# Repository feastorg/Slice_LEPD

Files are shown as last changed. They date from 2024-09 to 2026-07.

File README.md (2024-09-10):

# Photometer Slice

Photometer using LED and photodiode slice for BREAD.

## Introduction

[Short introduction on the project.]

## Usage

[Explain how to use the project. Include examples and screenshots if applicable.]

## Documentation

Please refer to the [docs](/docs) for more info.

---

<div align="center">
  <p>
    
    
  </p>
</div>

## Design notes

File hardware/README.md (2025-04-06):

# LED-Photodiode Optical Density Meter

## Parts

- LEDs
  - PD: SFH 213 FA
  - IR: INL-5AMIR15
  - from: https://forum.pioreactor.com/t/od600-or-900-what-is-the-part-number-for-the-ir-led-and-photodiode/375

## Subcomponents

1. **PWM-to-DAC Filter (Lower Left)**

   - **Input:** A PWM signal enters through an RC network (two resistors and two capacitors) that smooths it into a DC “DAC” voltage.
   - **Outputs:** This DAC voltage is fed to:
     - The noninverting (+) input of the LM339 comparator (top amplifier).
     - The noninverting (+) input of the MCP6242 op amp (bottom amplifier).

2. **LM339 Comparator (Top)**

   - **+ Input:** Receives the filtered DAC voltage.
   - **− Input:** Receives a reference or filtered voltage derived from the +5 V rail.
   - **Output:**
     - Uses an open-collector configuration with a pull-up resistor (1 kΩ) to the +5 V rail.
     - A 200 kΩ resistor from the output back to the DAC input provides hysteresis.
     - The comparator output drives the base of the BC858 PNP transistor through a 10 kΩ resistor.

3. **BC858 PNP Transistor (Top Switch)**

   - **Collector:** Connected directly to the +5 V rail.
   - **Base:** Driven by the LM339 comparator output (via a 10 kΩ resistor).
   - **Emitter:** Connected to the common output node, which is shared with:
     - The drain of the BSS806 N-channel MOSFET.
     - The cathode of the LED (which is further protected by a TVS diode).

4. **MCP6242 Op Amp (Bottom)**

   - **+ Input:** Receives the same DAC voltage from the PWM filter.
   - **− Input:** Connected to the source of the BSS806 MOSFET (the voltage sensed across a 10 Ω resistor).
   - **Output:** Drives the gate of the BSS806 MOSFET (labeled “FET_GATE”) to regulate current.

5. **BSS806 N-Channel MOSFET (Bottom Switch)**

   - **Drain:** Tied to the common output node (also the emitter of the BC858).
   - **Source:** Connects to a 10 Ω resistor that goes to ground. This resistor acts as a current-sense element.
   - **Function:** Controlled by the op amp to regulate the voltage at the source, and hence the current through the LED.

6. **LED and 10 Ω Sense Resistor**

   - **LED Anode:** Connected to the +5 V rail.
   - **LED Cathode:** Connected to the common node (junction of BC858 emitter and MOSFET drain).
   - **Current Path:** +5 V → LED → common node → MOSFET → 10 Ω resistor → Ground.
   - **Sensing:** The voltage across the 10 Ω resistor is used by the op amp for current regulation.

7. **TVS Diode (DF2S6.8M)**
   - **Connection:** Placed between the common output node and ground.
   - **Function:** Provides transient and ESD protection to the circuit.

---

## 2) Overall Function and How It Works

1. **PWM Filtering to Create a DAC:**  
   A low-pass RC filter converts a PWM signal into a stable DC voltage. This voltage represents the desired setpoint for the LED current or voltage.

2. **Op Amp and MOSFET Current Regulation:**

   - The MCP6242 op amp compares the DAC setpoint with the voltage at the MOSFET source (across the 10 Ω sense resistor).
   - Based on this comparison, the op amp adjusts the gate voltage of the BSS806 MOSFET.
   - This regulation maintains the correct current through the LED by ensuring that the sensed voltage (proportional to current) matches the DAC setpoint.

3. **Comparator and PNP Transistor Threshold Control:**

   - The LM339 comparator monitors the DAC voltage against a reference (from the +5 V supply).
   - Through its open-collector output (with hysteresis via the 200 kΩ resistor), it determines if the operating condition is within the desired range.
   - The comparator’s output drives the BC858 PNP transistor, which can provide an alternate current path or act as a switch to either enable or limit the LED current based on threshold conditions.

4. **Combined Regulation and Protection:**
   - **Current Flow:** The LED current flows from the +5 V rail through the LED, into the common node, through the MOSFET, and finally through the 10 Ω resistor to ground.
   - **Protection:** A TVS diode is connected at the output node to guard against voltage spikes.
   - **Feedback:** The op amp continuously adjusts the MOSFET’s gate voltage to ensure that the voltage across the 10 Ω resistor (and thus the LED current) matches the desired value set by the DAC voltage.

**In summary:**  
The circuit converts a PWM signal to a DC level that serves as a setpoint for LED current. The op amp and MOSFET form a linear regulator that adjusts the LED current, while the comparator and PNP transistor provide threshold-based switching or clamping for additional control and protection.

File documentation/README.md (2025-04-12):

# LED-Photodiode Optical Density Meter

## Parts

- LEDs
  - PD: SFH 213 FA
  - IR: INL-5AMIR15
  - from: https://forum.pioreactor.com/t/od600-or-900-what-is-the-part-number-for-the-ir-led-and-photodiode/375

- Connectors
  - Molex pico blade: https://www.digikey.ca/en/products/detail/molex/0530480210/242864?s=N4IgTCBcDaIKwGYAMAWAHEsBGJIC6AvkA

- LED driver sense resistor
  - https://www.digikey.ca/en/products/detail/stackpole-electronics-inc/RMCF1210FT10R0/1758534
  - 1/2W 1% 1210 (3225 Metric)

## LED Driver

Goal: drive an LED at a set constant current via a PWM signal to produce a consistent light level.

Purpose: we want the LED to emit a set light level with high accuracy (known) and precision (low noise).

### Subcomponents

1. **PWM-to-DAC Filter (Lower Left)**

   - **Input:** A PWM signal enters through an RC network (two resistors and two capacitors) that smooths it into a DC “DAC” voltage.
   - **Outputs:** This DAC voltage is fed to:
     - The noninverting (+) input of the LM339 comparator (top amplifier).
     - The noninverting (+) input of the MCP6242 op amp (bottom amplifier).

2. **LM339 Comparator (Top)**

   - **+ Input:** Receives the filtered DAC voltage.
   - **− Input:** Receives a reference or filtered voltage derived from the +5 V rail.
   - **Output:**
     - Uses an open-collector configuration with a pull-up resistor (1 kΩ) to the +5 V rail.
     - A 200 kΩ resistor from the output back to the DAC input provides hysteresis.
     - The comparator output drives the base of the BC858 PNP transistor through a 10 kΩ resistor.

3. **BC858 PNP Transistor (Top Switch)**

   - **Collector:** Connected directly to the +5 V rail.
   - **Base:** Driven by the LM339 comparator output (via a 10 kΩ resistor).
   - **Emitter:** Connected to the common output node, which is shared with:
     - The drain of the BSS806 N-channel MOSFET.
     - The cathode of the LED (which is further protected by a TVS diode).

4. **MCP6242 Op Amp (Bottom)**

   - **+ Input:** Receives the same DAC voltage from the PWM filter.
   - **− Input:** Connected to the source of the BSS806 MOSFET (the voltage sensed across a 10 Ω resistor).
   - **Output:** Drives the gate of the BSS806 MOSFET (labeled “FET_GATE”) to regulate current.

5. **BSS806 N-Channel MOSFET (Bottom Switch)**

   - **Drain:** Tied to the common output node (also the emitter of the BC858).
   - **Source:** Connects to a 10 Ω resistor that goes to ground. This resistor acts as a current-sense element.
   - **Function:** Controlled by the op amp to regulate the voltage at the source, and hence the current through the LED.

6. **LED and 10 Ω Sense Resistor**

   - **LED Anode:** Connected to the +5 V rail.
   - **LED Cathode:** Connected to the common node (junction of BC858 emitter and MOSFET drain).
   - **Current Path:** +5 V → LED → common node → MOSFET → 10 Ω resistor → Ground.
   - **Sensing:** The voltage across the 10 Ω resistor is used by the op amp for current regulation.

7. **TVS Diode (DF2S6.8M)**
   - **Connection:** Placed between the common output node and ground.
   - **Function:** Provides transient and ESD protection to the circuit.

---

### Function and Theory of Operation

1. **PWM Filtering to Create a DAC:**  
   A low-pass RC filter converts a PWM signal into a stable DC voltage. This voltage represents the desired setpoint for the LED current or voltage.

2. **Op Amp and MOSFET Current Regulation:**

   - The MCP6242 op amp compares the DAC setpoint with the voltage at the MOSFET source (across the 10 Ω sense resistor).
   - Based on this comparison, the op amp adjusts the gate voltage of the BSS806 MOSFET.
   - This regulation maintains the correct current through the LED by ensuring that the sensed voltage (proportional to current) matches the DAC setpoint.

3. **Comparator and PNP Transistor Threshold Control:**

   - The LM339 comparator monitors the DAC voltage against a reference (from the +5 V supply).
   - Through its open-collector output (with hysteresis via the 200 kΩ resistor), it determines if the operating condition is within the desired range.
   - The comparator’s output drives the BC858 PNP transistor, which can provide an alternate current path or act as a switch to either enable or limit the LED current based on threshold conditions.

4. **Combined Regulation and Protection:**
   - **Current Flow:** The LED current flows from the +5 V rail through the LED, into the common node, through the MOSFET, and finally through the 10 Ω resistor to ground.
   - **Protection:** A TVS diode is connected at the output node to guard against voltage spikes.
   - **Feedback:** The op amp continuously adjusts the MOSFET’s gate voltage to ensure that the voltage across the 10 Ω resistor (and thus the LED current) matches the desired value set by the DAC voltage.

**In summary:**  
The circuit converts a PWM signal to a DC level that serves as a setpoint for LED current. The op amp and MOSFET form a linear regulator that adjusts the LED current, while the comparator and PNP transistor provide threshold-based switching or clamping for additional control and protection.

## Photodiode Transimpedance amplifier

Goal: transduce the light level at the photodiode into a steady proportional current and transform this current into a proportional voltage that can be read.

Purpose: read the effective light level

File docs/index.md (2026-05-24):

---
title: "Slice LEPD Documentation"
description: "Overview and entry page for Slice LEPD project documentation."
nav_exclude: true
---

Welcome to the Slice LEPD project documentation.

## Board Renders

<figure style="display:inline-block; text-align:center; margin:10px;">
  Board Top
  <figcaption>Top</figcaption>
</figure>

<figure style="display:inline-block; text-align:center; margin:10px;">
  Board Bottom
  <figcaption>Bottom</figcaption>
</figure>

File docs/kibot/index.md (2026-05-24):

---
title: "KiBot Outputs"
description: "Index for KiBot-generated PCB artifacts."
layout: "page"
---

These are the docs & KiBot Outputs for Slice LEPD

The following files were generated from the latest PCB build:

- [Schematic.pdf](./Schematic.pdf)
- [PCB.pdf](./PCB.pdf)
- [kibot.log](./kibot.log)
- [BREAD_Slice-bom.html](./BREAD_Slice-bom.html)
- [BREAD_Slice-ibom.html](./BREAD_Slice-ibom.html)

_Last updated automatically by KiBot via GitHub Actions._

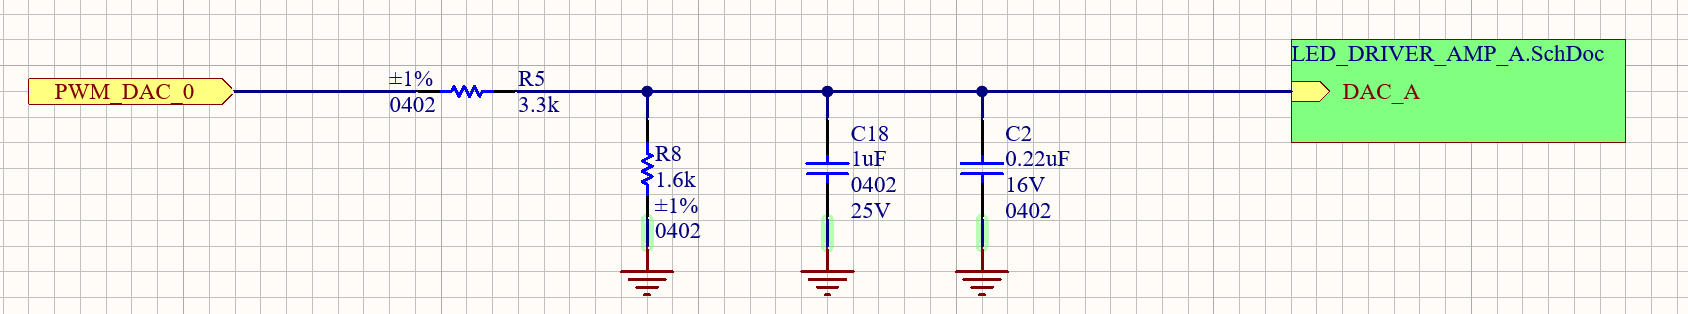
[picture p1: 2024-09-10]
hardware/pwm_dac0_to_led_driver_amp.png

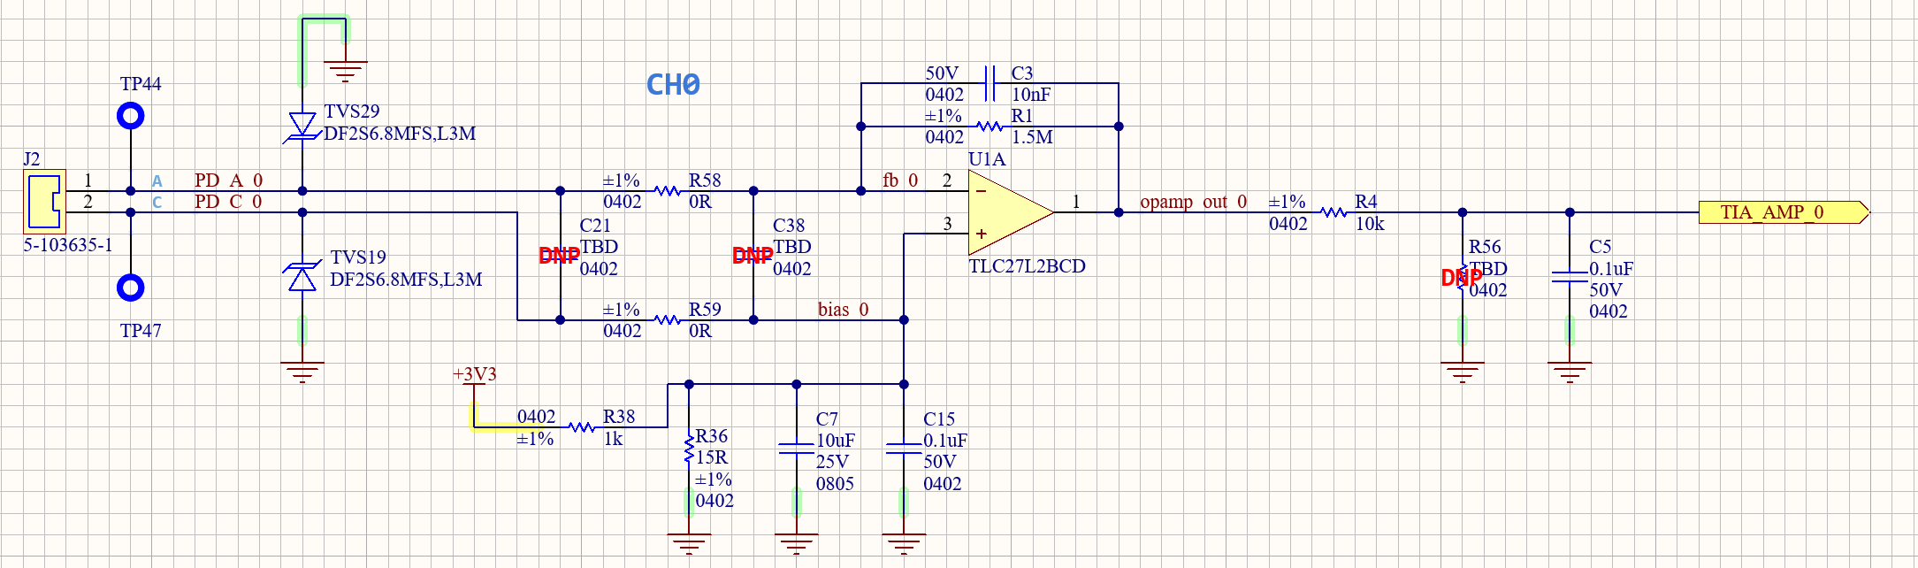
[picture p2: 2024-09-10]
hardware/pd_tia_amp.png

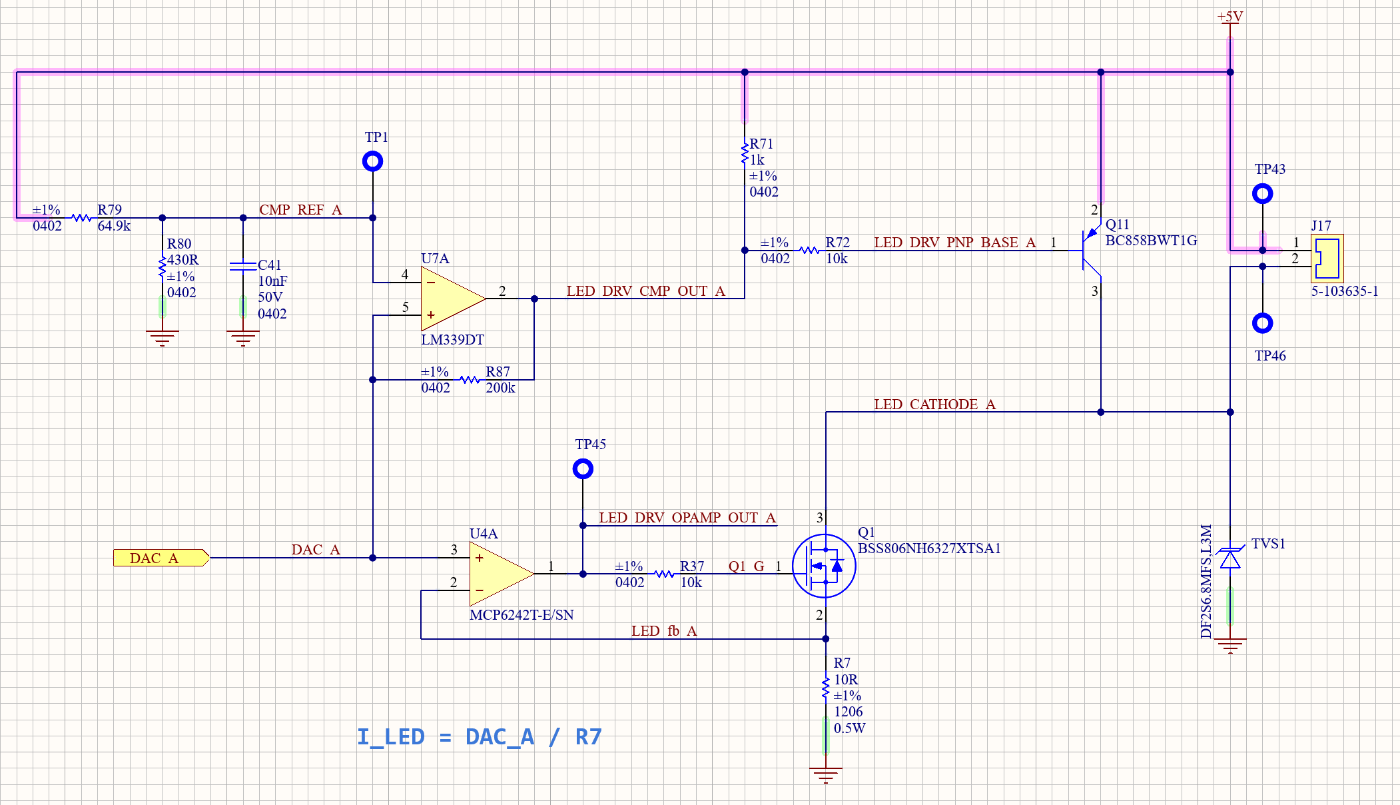
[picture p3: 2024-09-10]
hardware/led_driver_amp.png

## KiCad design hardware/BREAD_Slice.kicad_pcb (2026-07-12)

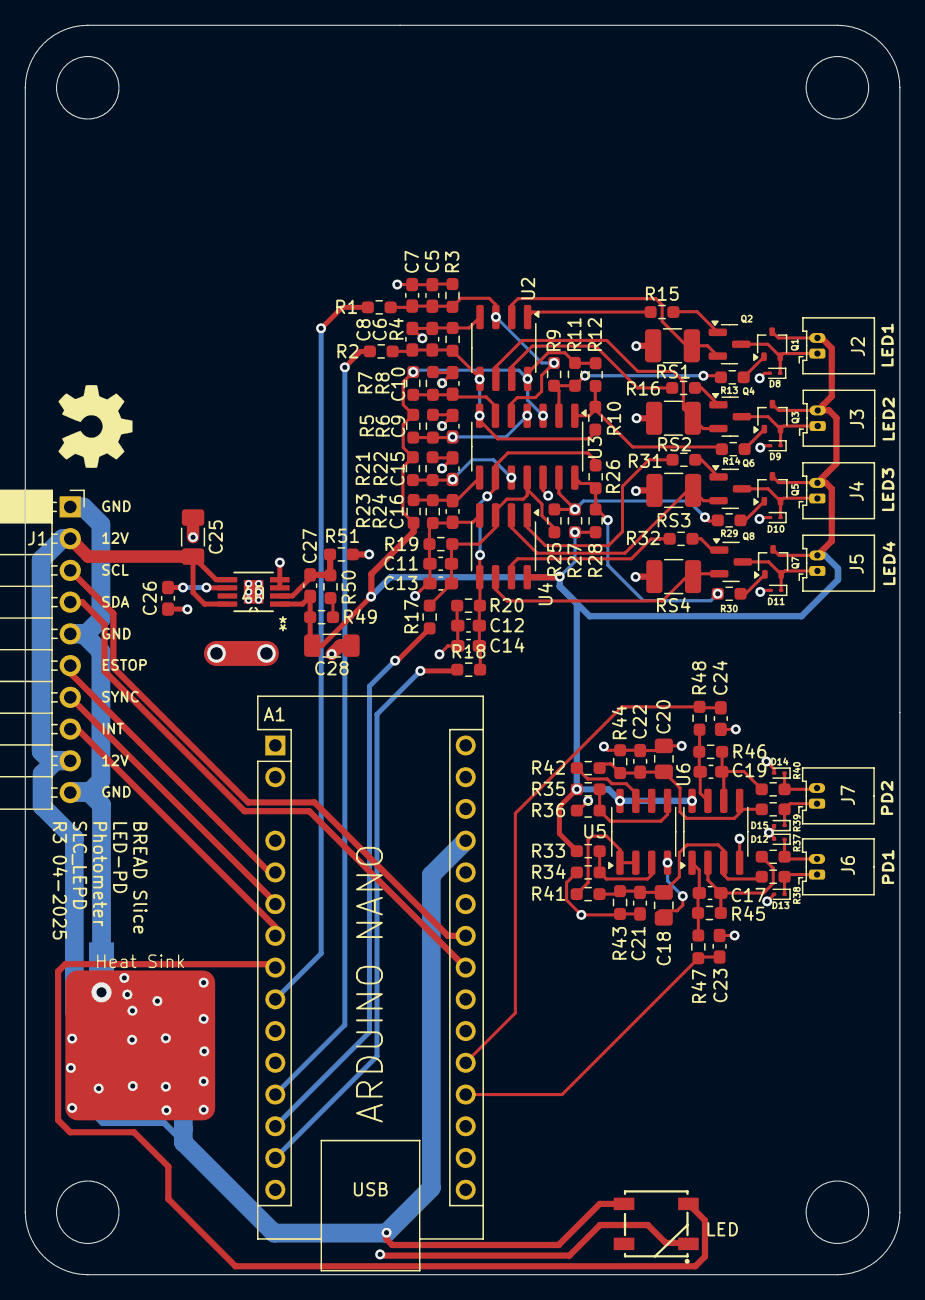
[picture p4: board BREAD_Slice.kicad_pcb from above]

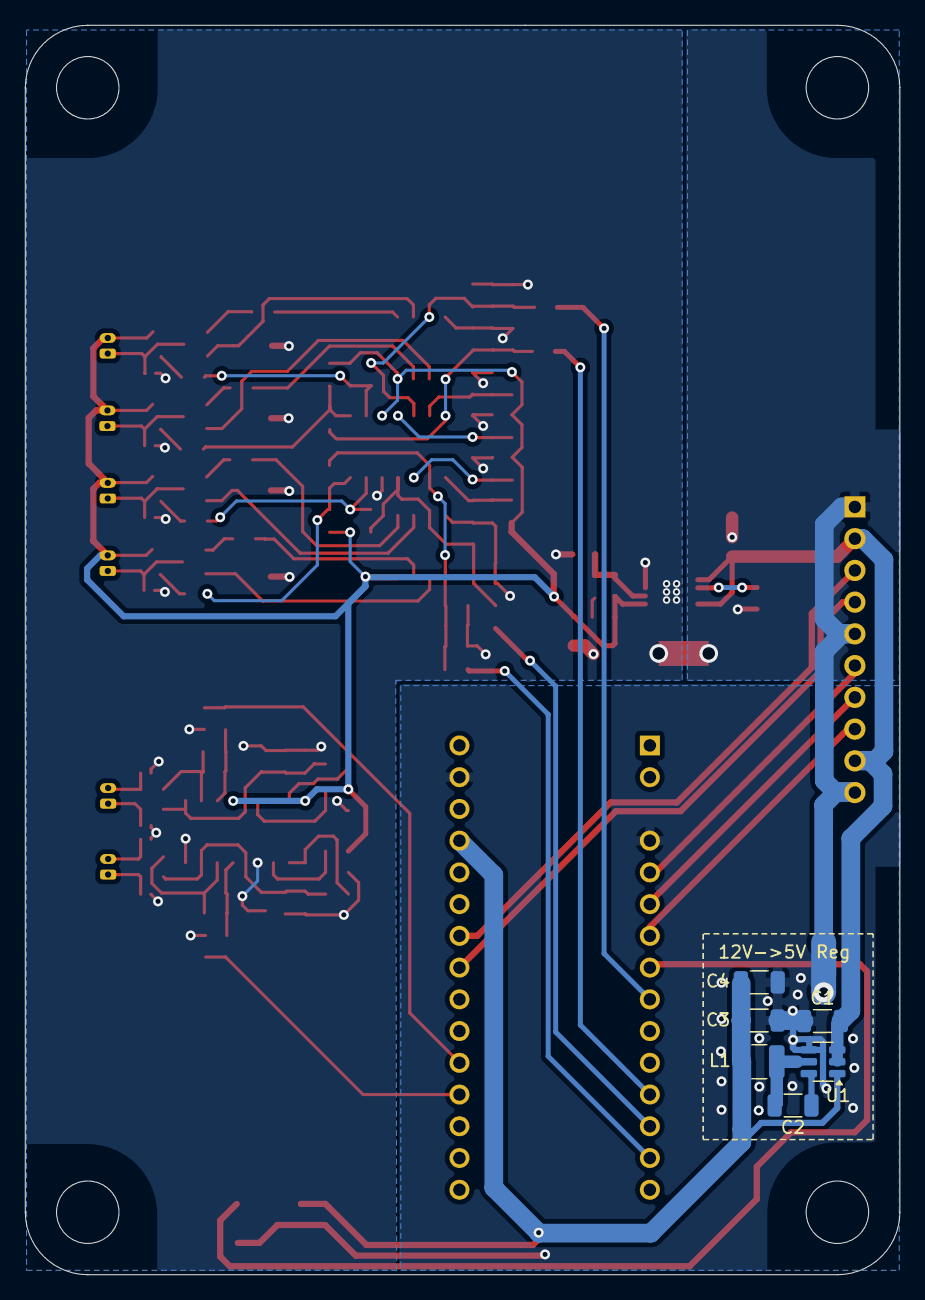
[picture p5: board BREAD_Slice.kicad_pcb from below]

Board: 2 copper layers, 70.0 x 100.0 mm, 124 parts (7 on the bottom side), 69 nets.

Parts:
A1: Arduino_Nano_v3.x; Arduino_Nano
C1, C3, C4: 22uF; C_1206_3216Metric
C2: 100nF; C_1206_3216Metric
C5, C6, C11, C12: 1u; C_0603_1608Metric_Pad1.08x0.95mm_HandSolder
C7, C8, C13, C14: 0.22u; C_0603_1608Metric_Pad1.08x0.95mm_HandSolder
C9, C10, C15, C16, C17, C19: 10n; C_0603_1608Metric_Pad1.08x0.95mm_HandSolder
C18, C20: 10u; C_0805_2012Metric_Pad1.18x1.45mm_HandSolder
C21, C22, C23, C24: 0.1u; C_0603_1608Metric_Pad1.08x0.95mm_HandSolder
C25, C28: 10u X7R; C_1206_3216Metric_Pad1.33x1.80mm_HandSolder
C26, C27: 10n X7R; C_0603_1608Metric_Pad1.08x0.95mm_HandSolder
D1: WS2812B_5050; WS2812-5050-4PIN
D8, D9, D10, D11, D12, D13, D14, D15: DF2S6.8MFS_L3M; D_SOD-923
H1, H2, H3, H4: MountingHole; MountingHole_5mm
HS1: Heatsink_Pad; Thermal_Pad
J1: Conn_01x10_Female; PinSocket_1x10_P2.54mm_Horizontal
J2, J3, J4, J5, J6, J7: Conn_01x02; Molex_PicoBlade_53048-0210_1x02_P1.25mm_Horizontal
L1: 4.7uH; L_1210_3225Metric
Logo1: Logo_Open_Hardware_Small; OSHW-Symbol_6.7x6mm_SilkScreen
NT1, NT2: NetTie_2; NetTie-2_SMD_Pad2.0mm
Q1, Q3, Q5, Q7: BC858BWT1G; SOT-323_SC-70
Q2, Q4, Q6, Q8: BSS806NH6327XTSA1; SOT-23
R1, R2, R17, R18: 3.3k 1%; R_0603_1608Metric_Pad0.98x0.95mm_HandSolder
R3, R4, R19, R20: 1.6k 1%; R_0603_1608Metric_Pad0.98x0.95mm_HandSolder
R5, R7, R21, R23: 64.9k 1%; R_0603_1608Metric_Pad0.98x0.95mm_HandSolder
R6, R8, R22, R24: 430 1%; R_0603_1608Metric_Pad0.98x0.95mm_HandSolder
R9, R10, R25, R26: 200k 1%; R_0603_1608Metric_Pad0.98x0.95mm_HandSolder
R11, R12, R27, R28, R41, R42: 1k 1%; R_0603_1608Metric_Pad0.98x0.95mm_HandSolder
R13, R14, R15, R16, R29, R30, R31, R32, R47, R48: 10k 1%; R_0603_1608Metric_Pad0.98x0.95mm_HandSolder
R33, R35: 10k; R_0603_1608Metric_Pad0.98x0.95mm_HandSolder
R34, R36: 20k; R_0603_1608Metric_Pad0.98x0.95mm_HandSolder
R37, R38, R39, R40: 0R; R_0603_1608Metric_Pad0.98x0.95mm_HandSolder
R43, R44: 15 1%; R_0603_1608Metric_Pad0.98x0.95mm_HandSolder
R45, R46: 1.5M 1%; R_0603_1608Metric_Pad0.98x0.95mm_HandSolder
R49: 300k 1%; R_0603_1608Metric_Pad0.98x0.95mm_HandSolder
R50: 71.5k 1%; R_0603_1608Metric_Pad0.98x0.95mm_HandSolder
R51: 100k 1%; R_0603_1608Metric_Pad0.98x0.95mm_HandSolder
RS1, RS2, RS3, RS4: 10 0.5W 1%; R_1210_3225Metric_Pad1.30x2.65mm_HandSolder
U1: AP63205; TSOT-23-6
U2, U4, U5: MCP6242T-E/SN; SOIC-8_3.9x4.9mm_P1.27mm
U3: LM339B; SOIC-14_3.9x8.7mm_P1.27mm
U6: TLV9142; SOIC-8_3.9x4.9mm_P1.27mm
U7: TPS7A4901DGNR; DGN8_1P89X1P57

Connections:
+5V: A1.27 (+5V), C3.2, C4.2, D1.1 (VDD), L1.2, U1.1 (FB)
+5VA: C27.2, C28.2, J2.2, J3.2, J4.2, J5.2, Q1.3 (C), Q3.3 (C), Q5.3 (C), Q7.3 (C), R5.2, R7.2, R11.1, R12.1, R21.2, R23.2, R27.1, R28.1, R33.1, R35.1, R49.2, U2.8 (V+), U3.3 (V+), U4.8 (V+), U5.8 (V+), U6.8 (V+), U7.1 (OUT)
+12V: C1.2, C25.2, J1.2, J1.9, U1.2 (EN), U1.3 (VIN), U7.5 (EN), U7.8 (IN)
/ESTOP: A1.5 (D2), J1.6
/I2C_CLK: A1.24 (A5), J1.3
/I2C_DAT: A1.23 (A4), J1.4
/INT: A1.6 (D3), J1.7
/LED: A1.8 (D5), D1.4 (DIN)
/Linear Constant‐Current LED Driver x4/COMP_OUT_1: R9.2, R11.2, R13.1, U3.2
/Linear Constant‐Current LED Driver x4/COMP_OUT_2: R10.2, R12.2, R14.1, U3.1
/Linear Constant‐Current LED Driver x4/COMP_OUT_3: R25.2, R27.2, R29.1, U3.13
/Linear Constant‐Current LED Driver x4/COMP_OUT_4: R26.2, R28.2, R30.1, U3.14
/Linear Constant‐Current LED Driver x4/COMP_REF_1: C9.1, R5.1, R6.1, U3.4 (-)
/Linear Constant‐Current LED Driver x4/COMP_REF_2: C10.1, R7.1, R8.1, U3.6 (-)
/Linear Constant‐Current LED Driver x4/COMP_REF_3: C15.1, R21.1, R22.1, U3.10 (-)
/Linear Constant‐Current LED Driver x4/COMP_REF_4: C16.1, R23.1, R24.1, U3.8 (-)
/Linear Constant‐Current LED Driver x4/DAC_1: C5.1, C7.1, R1.2, R3.1, R9.1, U2.3 (+), U3.5 (+)
/Linear Constant‐Current LED Driver x4/DAC_2: C6.1, C8.1, R2.2, R4.1, R10.1, U2.5 (+), U3.7 (+)
/Linear Constant‐Current LED Driver x4/DAC_3: C11.1, C13.1, R17.2, R19.1, R25.1, U3.11 (+), U4.3 (+)
/Linear Constant‐Current LED Driver x4/DAC_4: C12.1, C14.1, R18.2, R20.1, R26.1, U3.9 (+), U4.5 (+)
/Linear Constant‐Current LED Driver x4/FEEDBACK_1: Q2.2 (S), RS1.1, U2.2 (-)
/Linear Constant‐Current LED Driver x4/FEEDBACK_2: Q4.2 (S), RS2.1, U2.6 (-)
/Linear Constant‐Current LED Driver x4/FEEDBACK_3: Q6.2 (S), RS3.1, U4.2 (-)
/Linear Constant‐Current LED Driver x4/FEEDBACK_4: Q8.2 (S), RS4.1, U4.6 (-)
/Linear Constant‐Current LED Driver x4/LED_CATHODE_1: D8.1, J2.1, Q1.2 (E), Q2.3 (D)
/Linear Constant‐Current LED Driver x4/LED_CATHODE_2: D9.1, J3.1, Q3.2 (E), Q4.3 (D)
/Linear Constant‐Current LED Driver x4/LED_CATHODE_3: D10.1, J4.1, Q5.2 (E), Q6.3 (D)
/Linear Constant‐Current LED Driver x4/LED_CATHODE_4: D11.1, J5.1, Q7.2 (E), Q8.3 (D)
/Linear Constant‐Current LED Driver x4/NFET_GATE_1: Q2.1 (G), R15.2
/Linear Constant‐Current LED Driver x4/NFET_GATE_2: Q4.1 (G), R16.2
/Linear Constant‐Current LED Driver x4/NFET_GATE_3: Q6.1 (G), R31.2
/Linear Constant‐Current LED Driver x4/NFET_GATE_4: Q8.1 (G), R32.2
/Linear Constant‐Current LED Driver x4/OPAMP_OUT_1: R15.1, U2.1
/Linear Constant‐Current LED Driver x4/OPAMP_OUT_2: R16.1, U2.7
/Linear Constant‐Current LED Driver x4/OPAMP_OUT_3: R31.1, U4.1
/Linear Constant‐Current LED Driver x4/OPAMP_OUT_4: R32.1, U4.7
/Linear Constant‐Current LED Driver x4/PNPBJT_BASE_1: Q1.1 (B), R13.2
/Linear Constant‐Current LED Driver x4/PNPBJT_BASE_2: Q3.1 (B), R14.2
/Linear Constant‐Current LED Driver x4/PNPBJT_BASE_3: Q5.1 (B), R29.2
/Linear Constant‐Current LED Driver x4/PNPBJT_BASE_4: Q7.1 (B), R30.2
/PD1: A1.19 (A0), C23.1, R47.2
/PD2: A1.20 (A1), C24.1, R48.2
/PWM1: A1.9 (D6), R1.1
/PWM2: A1.12 (D9), R2.1
/PWM3: A1.13 (D10), R17.1
/PWM4: A1.14 (D11), R18.1
/Photodiode TIA Amplifier x2/3V3_2: R42.1, U5.6 (-), U5.7
/Photodiode TIA Amplifier x2/+3V3_1: R41.1, U5.1, U5.2 (-)
/Photodiode TIA Amplifier x2/PD_ANODE1: D12.1, J6.2, R37.1
/Photodiode TIA Amplifier x2/PD_ANODE2: D14.1, J7.2, R39.1
/Photodiode TIA Amplifier x2/PD_CATHODE1: D13.1, J6.1, R38.1
/Photodiode TIA Amplifier x2/PD_CATHODE2: D15.1, J7.1, R40.1
/Photodiode TIA Amplifier x2/TIA_BIAS_1: C18.1, C21.1, R38.2, R41.2, R43.1, U6.3 (+)
/Photodiode TIA Amplifier x2/TIA_BIAS_2: C20.1, C22.1, R40.2, R42.2, R44.1, U6.5 (+)
/Photodiode TIA Amplifier x2/TIA_FEEDBACK_1: C17.1, R37.2, R45.1, U6.2 (-)
/Photodiode TIA Amplifier x2/TIA_FEEDBACK_2: C19.1, R39.2, R46.1, U6.6 (-)
/Photodiode TIA Amplifier x2/TIA_OUT_1: C17.2, R45.2, R47.1, U6.1
/Photodiode TIA Amplifier x2/TIA_OUT_2: C19.2, R46.2, R48.1, U6.7
/SYNC: A1.7 (D4), J1.8
GND: A1.4 (GND), A1.29 (GND), C1.1, C3.1, C4.1, D1.3 (VSS), HS1.1, NT1.1, U1.4 (GND)
GNDA: C5.2, C6.2, C7.2, C8.2, C9.2, C10.2, C11.2, C12.2, C13.2, C14.2, C15.2, C16.2, C18.2, C20.2, C21.2, C22.2, C23.2, C24.2, C28.1, D8.2, D9.2, D10.2, D11.2, D12.2, D13.2, D14.2, D15.2, NT2.2, R3.2, R4.2, R6.2, R8.2, R19.2, R20.2, R22.2, R24.2, R34.2, R36.2, R43.2, R44.2, R51.1, RS1.2, RS2.2, RS3.2, RS4.2, U2.4 (V-), U3.12 (V-), U4.4 (V-), U5.4 (V-), U6.4 (V-), U7.3 (NC), U7.4 (GND), U7.EPAD
GNDPWR: C25.1, C26.1, J1.1, J1.5, J1.10, NT1.2, NT2.1
unnamed: R49.1, R50.2
unnamed: C2.2, U1.6 (BST)
unnamed: C2.1, L1.1, U1.5 (SW)
unnamed: R33.2, R34.1, U5.3 (+)
unnamed: R35.2, R36.1, U5.5 (+)
unnamed: C27.1, R50.1, R51.2, U7.2 (FB)
unnamed: C26.2, U7.6 (NR/SS)

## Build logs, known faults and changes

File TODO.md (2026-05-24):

# TODO

## Pass 1 — CI Pipeline

- [x] Pipeline added
- [x] DRC: FAIL — 2 clearance violations (zone clearance 0.5mm, actual ~0.475-0.488mm)
- [x] ERC: PASS
- [ ] Fab: SKIPPED (blocked by DRC pre-flight)
- [ ] gen-kibot-index: SKIPPED
- [ ] deploy-pages: SKIPPED

## Pass 2 — Pre-Fab Review

- [ ] Fix 2x zone clearance violations (increase spacing or reduce zone clearance rule)
- [ ] Verify BOM completeness and sourcing
- [ ] Confirm board outline and mounting holes
- [ ] Footprint verification against datasheets
- [ ] Design review sign-off

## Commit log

2025-04-05 added opamps
    [BREAD_Slice.kicad_pcb, BREAD_Slice.kicad_sch]
2025-04-06 completed CC driver for LEDs
    [BREAD_Slice.kicad_sch, linear_cc_led_driver.kicad_sch]
2025-04-12 finalized initial schematic and board
    [BREAD_Slice.kicad_pcb, BREAD_Slice.kicad_sch, linear_cc_led_driver.kicad_sch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]
2026-07-12 chore(hw): migrate KiCad files to the KiCad 10 format
    Via `kicad-cli sch upgrade` / `pcb upgrade` (bread-infra
    scripts/upgrade_kicad10.sh). Verified lossless: identical netlist, footprint
    positions and routing.
    Note `sch upgrade` does not cascade into hierarchical sub-sheets, so every
    .kicad_sch is upgraded individually -- upgrading only the root sheet leaves
    sub-sheets on the old format, which looks migrated and is not.
    [BREAD_Slice.kicad_pcb, BREAD_Slice.kicad_sch, linear_cc_led_driver.kicad_sch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]
2026-07-12 fix(hw): fail DRC on schematic/PCB footprint mismatch
    KiCad's stock default severity for footprint_symbol_mismatch is `warning`
    (board_design_settings.cpp:189), and KiBot's DRC preflight only fails on
    errors. So `schematic_parity: true` ran the check and could never fail it --
    a mismatch was reported on every CI run for months, buried in ~100 warnings,
    and every run went green.
    Raising it to `error` makes the parity gate real.
2026-07-12 chore: gitignore KiCad 10 local history
    KiCad 10 added a Local History feature. On first save it creates
    <project>/.history and calls git_repository_init() on it, so the directory is
    a nested git repository. KiCad writes a .gitignore inside it, but that governs
    KiCad's own history repo -- this repo still sees an embedded repository and
    reports it untracked. Committing it would add a broken gitlink.
2026-07-12 fix(hw): re-point stale library nicknames
    These parts exist in KiCad-Master-Lib; the boards referenced libraries that no
    longer exist (kml-custom, KML-Custom, and SparkFun libraries that never
    contained the part) or names the library has since changed.
    KiCad embeds footprint geometry in the .kicad_pcb, so the boards rendered and
    fabricated correctly and the rot stayed invisible -- it only surfaces on
    update-from-library, or when a generator tries to resolve a nickname.
    Nickname/name only. No geometry is changed:
    SparkFun-DiscreteSemi:AP63205 -> KMLib_IC_Power:AP63205WU-7_Buck_Regulator
    SparkFun-LED:WS2812-5050-4PIN -> KMLib_IC_SMD:WS2812-5050-4PIN
    kml-custom:DGN8_1P89X1P57 -> KMLib_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
    [BREAD_Slice.kicad_pcb, BREAD_Slice.kicad_sch, tps7a4901.kicad_sch]
2026-07-12 chore: stop tracking .kicad_prl
    KiCad rewrites .kicad_prl on every project open -- open sheet, zoom level,
    selection filter. It is per-developer local state, not design intent, so
    tracking it means the working tree goes dirty every time anyone opens the board.
2026-07-12 ci: gate on board validation and run on pull requests
    - add the validate-board job: KiCad 10 format, a real (error-severity) DRC
    parity gate, every library reference resolving, un-swapped Makefile targets,
    and .history/.kicad_prl gitignored. Green means the board is done.
    - run on pull_request, not just push to main. Hardware checks previously ran
    only AFTER a change had merged: they could report that main was broken, but
    never stop it from breaking. A gate that only fires post-merge is a
    notification, not a gate.
    - pin bread-infra to v1.0.0 rather than @main, so a bread-infra commit cannot
    silently change what this PR is gated on.
2026-07-12 chore: gitignore KiCad 10 generated and lock files
    KiCad 10 adds design-block libraries and generates a design-block-lib-table
    alongside fp-lib-table and sym-lib-table. Like those, it holds absolute paths,
    so it is machine-local and generated -- never committed.
    Also ignores KiCad's project lock file (~<project>.kicad_pro.lck), written
    whenever a project is open.
    The existing .gitignore predates KiCad 10 and covered neither, so simply opening
    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
2026-07-12 fix(hw): repair symbol sub-unit name prefixes
    The library re-point renamed symbols in lib_symbols from LIB:OLD to LIB:NEW,
    but a symbol's sub-units carry the bare item name:
    (symbol "KMLib_IC_Power:AP63205WU-7_Buck_Regulator"
    (symbol "AP63205_0_1" ...) <- still the old prefix
    KiCad requires every sub-unit to be named "<parent item>_<unit>_<style>", so any
    symbol whose ITEM name changed (not merely its library) failed to load:
    Invalid symbol unit name prefix AP63205_0_1
    Rename each sub-unit to match its parent. Nickname-only re-points were never
    affected -- their item name is unchanged.
    Note kicad-cli reports "Failed to load schematic" and still EXITS 0, so this was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
    [BREAD_Slice.kicad_sch, tps7a4901.kicad_sch]
2026-07-12 ci: pin bread-infra v1.1.0
    v1.1.0 adds the schematic-load check. kicad-cli prints 'Failed to load
    schematic' and still exits 0, so an unloadable schematic scored as zero ERC
    violations -- 34 boards were unopenable while every automated check said they
    were fine. validate-board now runs in the KiCad container and actually loads
    every sheet.
2026-07-13 fix(hw): use the canonical 2-layer KiBot config
    config.kibot.yaml had drifted into five variants across the fleet. Three differed
    only in trailing comments; the two real variants are 2-layer and 4-layer.
    Adopts bread-infra templates/config.kibot.2-layer.yaml, chosen from the board's
    actual copper layer count (2).
    Also pins bread-infra to v1.2.0, which adds a validate-board check that a board
    must plot every copper layer it has.
